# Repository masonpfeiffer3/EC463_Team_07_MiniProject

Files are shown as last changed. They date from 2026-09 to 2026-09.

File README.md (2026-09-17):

# 07-Miniproject
[Demo Link](https://drive.google.com/file/d/174wR8b0HiahtT9Z3u5mZbhheMCSKgrk_/view?usp=sharing)

[Project Board Link (responsibilities listed here)](https://app.notion.com/p/Mini-Project-Board-3da2b21b7a02809690e9f732688cc1ad?source=copy_link)

## Product Photo

<p align="center">
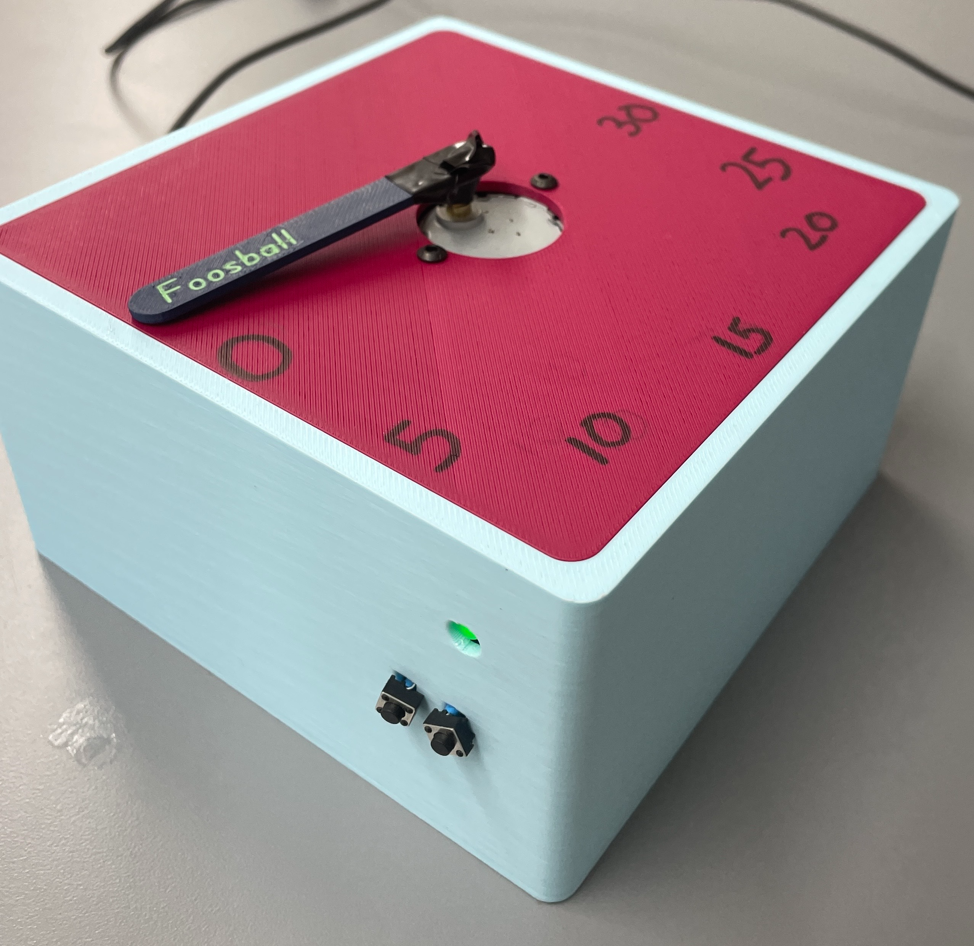
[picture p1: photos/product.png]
  
</p>

## How to Use

The device has two buttons (A and B) and one RGB status LED. On power-up the pointer is assumed to be parked at the home/reset position (0°).

1. **Idle / Time Select** — LED glows steady green.
   - Press **Button A** to cycle through the four presets (15, 20, 25, 30 min). Each press drives the stepper motor to move the pointer to that preset's angle.
   - Press **Button B** to start the countdown for the currently selected preset.
2. **Count Down** — LED flashes green.
   - The pointer sweeps continuously from the preset angle back toward the home position over the course of the countdown, arriving back at 0° exactly at timeout.
   - Press **Button A** to reset immediately (pointer returns home, state returns to idle).
   - Press **Button B** to pause.
3. **Pause** — LED flashes red/green.
   - Press **Button A** to reset (pointer returns home).
   - Press **Button B** to resume the countdown from where it left off.

### Building blocks demonstrated

- **GPIO** — both buttons are read as debounced digital inputs, and the microcontroller's output pins drive the L293D motor driver's control lines; GPIO is the foundation every other subsystem (motor, LED, buttons) is built on.
- **PWM** — the RGB LED's steady/flashing states are produced by driving each color's GPIO pin with a PWM duty cycle that ramps up and down (`PulsingRGB` in `firmware/angle_config.py`, prototyped in `firmware/led.py`).
- **Motor control** — a 28BYJ-48 stepper motor, wave-driven through an L293D H-bridge (`Stepper28BYJ48` in `firmware/angle_config.py`), moves the clock-hand pointer to precise preset angles and sweeps it proportionally during the countdown.
- **Low-power operation** — the stepper's coils are de-energized (`release()`) as soon as a move completes, so the motor only draws current (and generates heat) while actively stepping rather than continuously holding torque at a fixed position.

## Repository Structure

```
.
├── firmware/                # Micro source code
├── Hardware/
│   ├── Electrical/          # Schematics, wiring diagrams, and component docs
│   └── Mechanical/          # Enclosure CAD/STL files and drawings
├── photos/                  # All project images (schematics, CAD drawings, product photos, etc.)
└── README.md
```

## Flow Chart & Electrical Schematic

<p align="center">
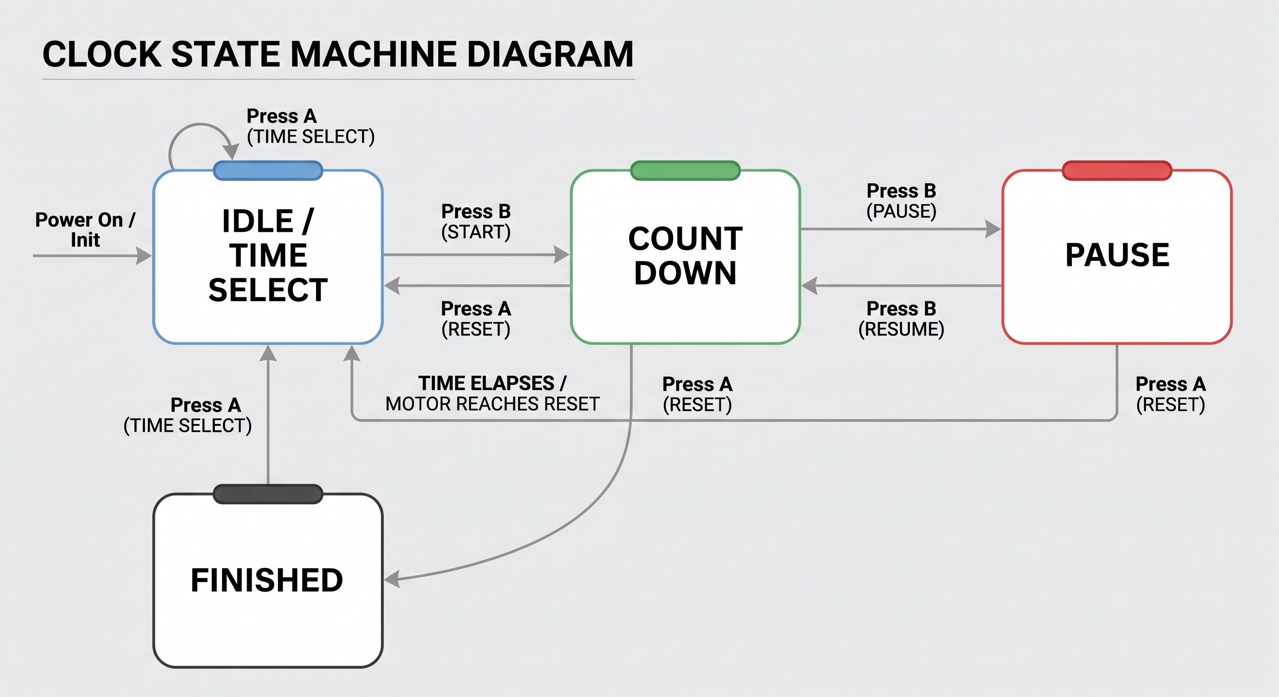
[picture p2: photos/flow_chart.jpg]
  
  
</p>

## Approach & Progress

After setting up the team repo with a branch protection ruleset for `main`, development started on the breadboard circuitry needed to interface with the embedded hardware alongside the software prototype.

This was built up one step at a time:

1. Verified the ESP32-S3 could be flashed via Thonny MicroPython with a simple blink test on the onboard LED.
2. Wired the necessary GPIO pins to the motor controller, including grounding, supplying voltage, and tying the enable pins high, then connected the motor to the controller.
3. Tested with a simple script that spun the motor 90° back and forth based on its gear ratio.
4. Attached the push buttons to additional I/O and continuously ran the motor until a button press was detected (with software debouncing) — one button reverses direction, the other pauses/resumes motion.
5. Connected 3 GPIO pins to each RGB LED anode prong (through resistors) and grounded the cathode, then drove PWM signals to the GPIO pins to experiment with flashing frequencies.
6. Implemented the finite state machine for operation — the core of the project. With all other embedded components functioning, wiring up the clock-specific use case was trivial beyond the state machine itself.

The software/embedded prototype now exists, and the rest of the team can carry it forward to the final version.

### Design Intentionality and Tradeoffs

| State | LED | Button A | Button B |
|---|---|---|---|
| Idle / Time Select | Blue | Time select | Start |
| Count Down | Green | Reset | Pause |
| Pause | Red | Reset | Resume |

In the idle state, the pointer indicates the selected time in 360°/5 = 72° increments (requiring a clock face labeled at each position). Upon start, the pointer moves from the selected time position to the reset position. There are 5 total positions — 4 time options plus the reset position.

There are multiple ways to lay out these positions, and the tradeoff considered here is that total movement isn't proportional to the selected time (15 min is 72° from reset, 20 min is 144°, etc.), but functionally the user can still gauge the proportion of time that has passed since the timer started.

<p align="center">
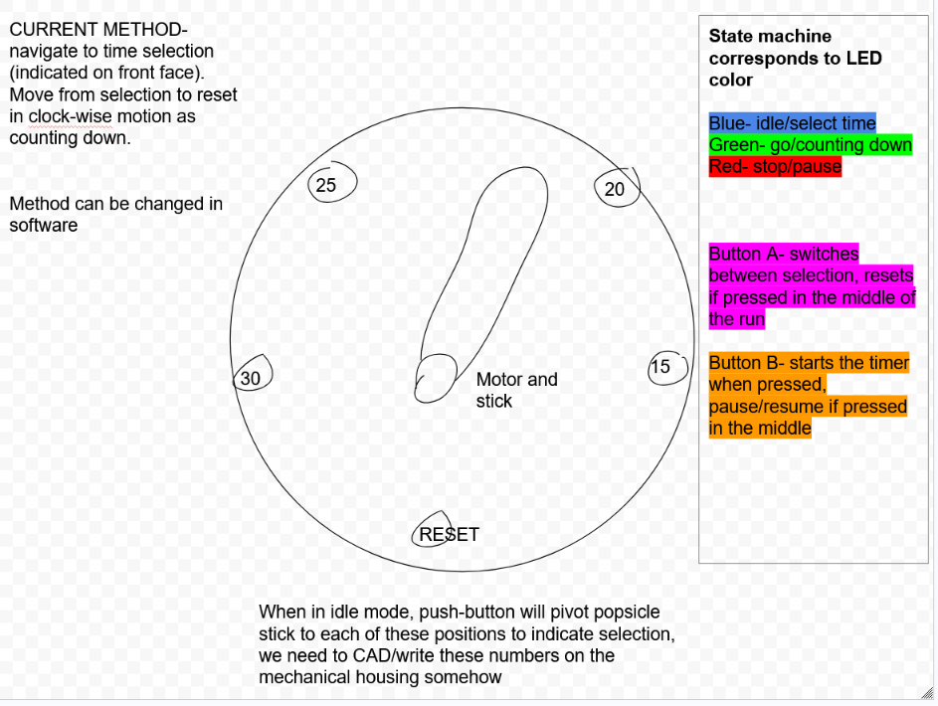
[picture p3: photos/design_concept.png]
  
</p>

**Update:** the final version changed this so the countdown is proportional. Even though only 15/20/25/30 are selectable times, the dial reserves the space for 5 and 10 minutes between each selection and the reset (0) position — so the pointer's distance from reset always reflects how much time is actually left, regardless of which time was selected.

## Team

| Role | Named Members |
|---|---|
| Mechanical Housing | Lana Kader, Niyati Patel, Arham Mufti |
| Electrical Wiring | Lana Kader, Mason Pfeiffer, Ethan Manfredi |
| uController Firmware | Darwin Quizhpi, Phillip Omohundro, Mason Pfeiffer, Ethan Manfredi |

[Project Board Link (responsibilities listed here)](https://app.notion.com/p/Mini-Project-Board-3da2b21b7a02809690e9f732688cc1ad?source=copy_link)

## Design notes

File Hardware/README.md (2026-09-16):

## Hardware

This folder is divided into two sections:

* **[Electrical](./Electrical/)** — schematics, wiring, and the electronic components used (microcontroller, motor driver, LEDs, buttons).
* **[Mechanical](./Mechanical/)** — enclosure CAD/STL files and drawings.

See each subfolder's README for details.

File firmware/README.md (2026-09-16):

Flow Chart

this folder contains firmware that to flash to the ESP32 S3, in order of development prototyping

**`angle_config.py` is the actual/final firmware.** `stepper.py`, `push_button.py`, `led.py`, and `state_machine.py` are earlier iterations kept for reference — each one built up a single piece (motor motion, button input, LED, then the combined state machine) on the way to the final version.

1. stepper.py drives the stepper 90 degrees back and forth
2. push_button.py actively runs the motor and reverses it's direction upon button press
3. led.py flashes the LED between it's colors using PWM
4. state_machine.py combines these features to create the timer
5. angle_config.py is the final version — same state machine, but with proportional preset angles (see below)

state machine-
- LED color corresponds to state
- blue = idle (one button cycles through time select, the other starts)
- green = active (one button resets it, the other pauses)
- red = paused (one button resets it, the other resumes)

Each time has it's own position, as well as the reset position, which upon starting the stepper motor moves toward.
5 total positions- 15, 20, 25, 30, and the reset position.

In the final version (`angle_config.py`), each preset's angle is proportional to its duration (6° per minute: 15 min = 90°, 20 min = 120°, 25 min = 150°, 30 min = 180°), so the hand's distance from the reset position always reflects how much time is actually remaining, not just which preset was picked.

stepper.py-
The firmware file stepper.py contains a test for the micro controller that is intended to turn the stepper motor 90º in one direction and then 90º back to its original position. This test allows us to ensure that our wiring is correct and that we engage the correct motor pins to allow us to move the motor.

At the top of the file is the pinout that specifies which GPIO port is connected to which pin and which wire each of those pins is connected to. We then define the steps per revolution which is needed to specify how much each step rotates the rod.

Finally, we execute the rotation, turning 90º in the positive direction before pausing and turning back

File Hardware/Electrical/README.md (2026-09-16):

# Wiring schematic 

<p align="center">

</p>

# Parts Used in the Project

<p align="center">
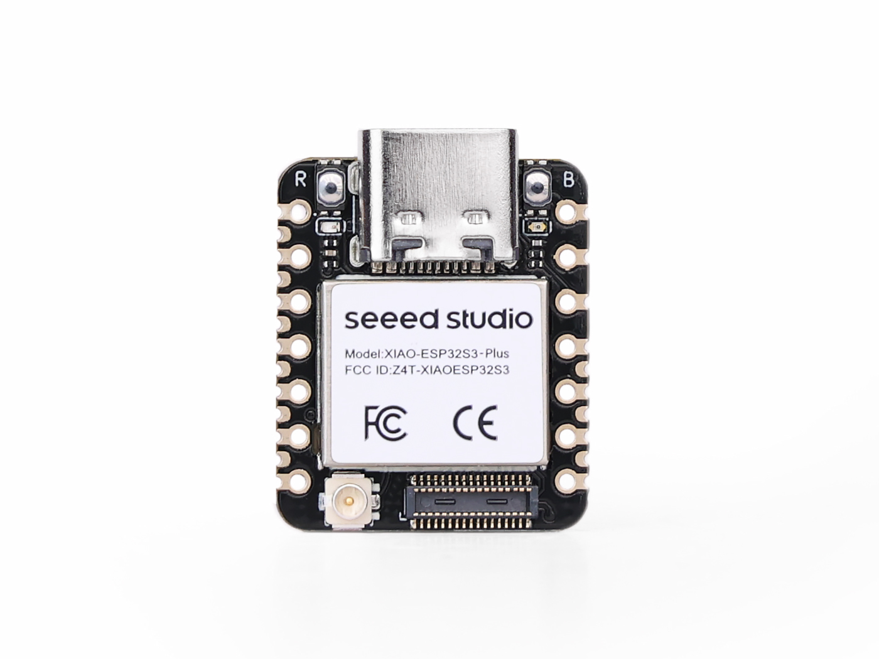
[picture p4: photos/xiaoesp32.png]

</p>

<p align="center">
<strong>XIAO ESP32-S3</strong>
</p>

The XIAO ESP32-S3 is the main microcontroller used in the project. It runs the program and controls the other components by reading inputs and sending output signals.

---

<p align="center">
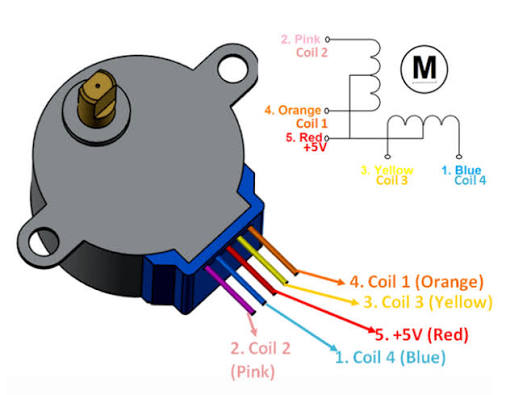
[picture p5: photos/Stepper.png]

</p>

<p align="center">
<strong>28BYJ-48 Stepper Motor</strong>
</p>

The 28BYJ-48 is a small stepper motor that can rotate in precise steps. It is used when controlled movement and positioning are needed.

---

<p align="center">
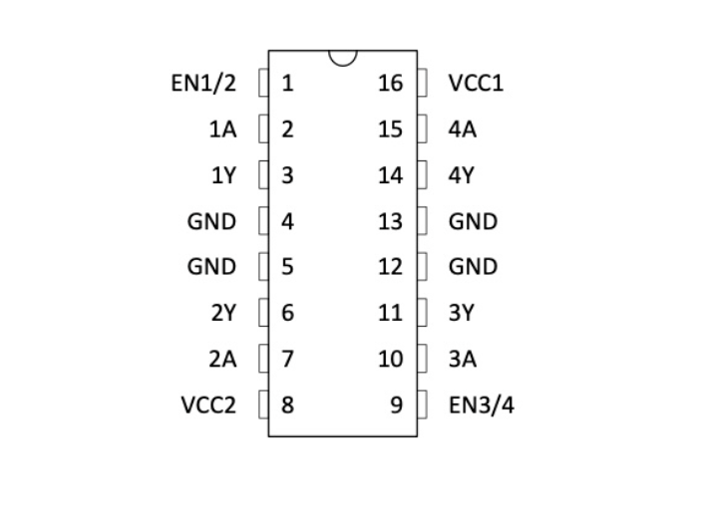
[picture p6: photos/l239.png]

</p>

<p align="center">
<strong>L293 Motor Driver</strong>
</p>

The L293 is a motor driver used between the ESP32 and the stepper motor. It allows the microcontroller to control the motor while providing the higher current required by the motor.

---

<p align="center">
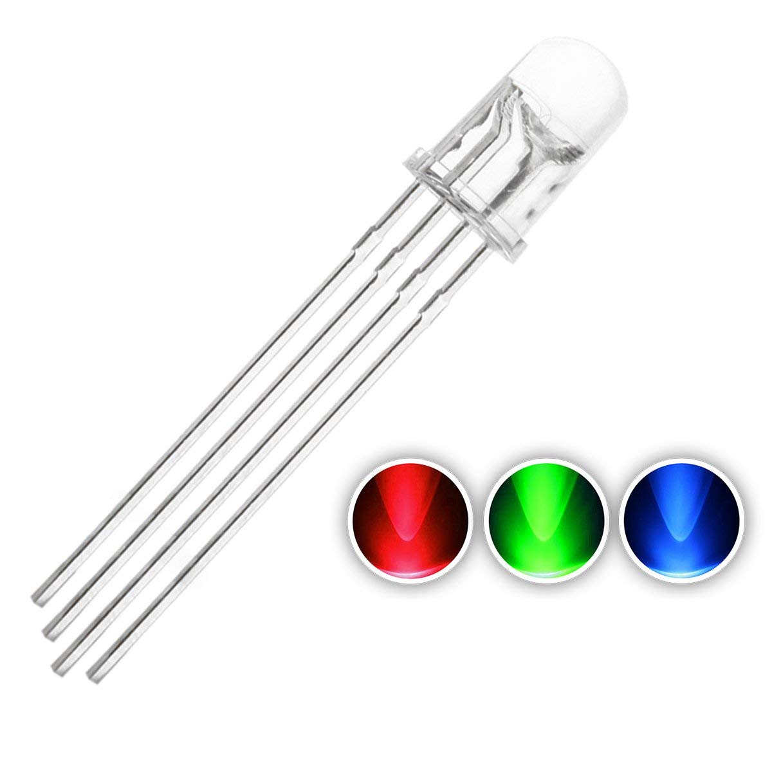
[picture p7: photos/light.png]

</p>

<p align="center">
<strong>4-Pin RGB LED</strong>
</p>

The RGB LED contains red, green, and blue LEDs in one package. By controlling each color individually, it can display different colors and provide visual feedback about the system.

---

<p align="center">
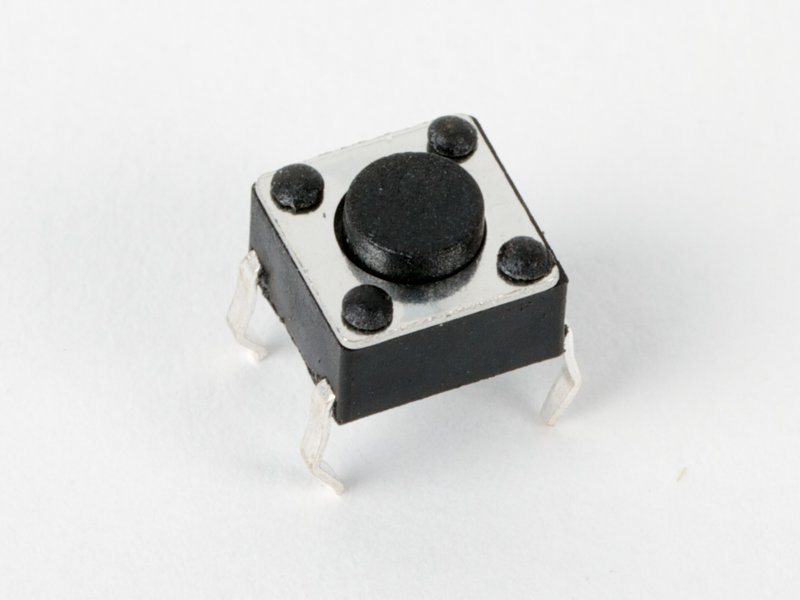
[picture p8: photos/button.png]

</p>

<p align="center">
<strong>Push Buttons</strong>
</p>

Two push buttons are used as user inputs. When pressed, they send a signal to the ESP32 so the program can perform a specific action.

# How These Parts Were Connected

Connections:

| Component | Connected To |
|---|---|
| XIAO GPIO1–4 | L293D inputs (1A, 2A, 3A, 4A) |
| L293D outputs (1Y, 2Y, 3Y, 4Y) | Stepper motor coils (Orange, Pink, Yellow, Blue) |
| Motor red wire | +5V |
| L293D Pin 16 (VCC1) | +3.3V (logic power) |
| L293D Pin 8 (VCC2) | +5V (motor power) |
| L293D Pins 1 & 9 (EN) | +3.3V (enables motor channels) |
| L293D Pins 4, 5, 12, 13 | GND |
| XIAO GPIO7 | Red LED (through 220Ω resistor) |
| XIAO GPIO8 | Blue LED (through 220Ω resistor) |
| XIAO GPIO9 | Green LED (through 220Ω resistor) |
| XIAO GPIO5 | Button 1 |
| XIAO GPIO6 | Button 2 |
| All GND pins | Common ground |
| Stepper motor shaft | Popsicle stick (clock hand) |

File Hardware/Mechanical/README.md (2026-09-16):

# Mechanical Design

<p align="center">
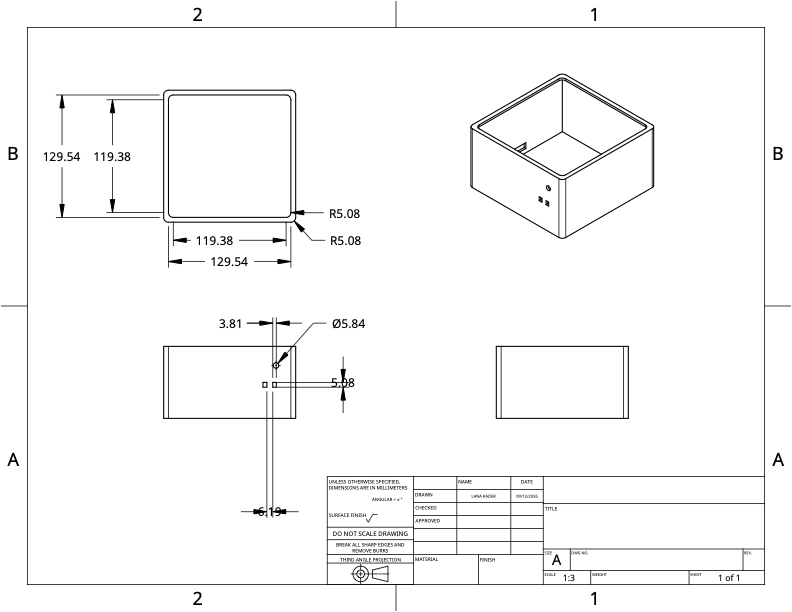
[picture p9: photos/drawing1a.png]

</p>

<p align="center">
<strong>Main Box Enclosure Drawing</strong>
</p>

<p align="center">
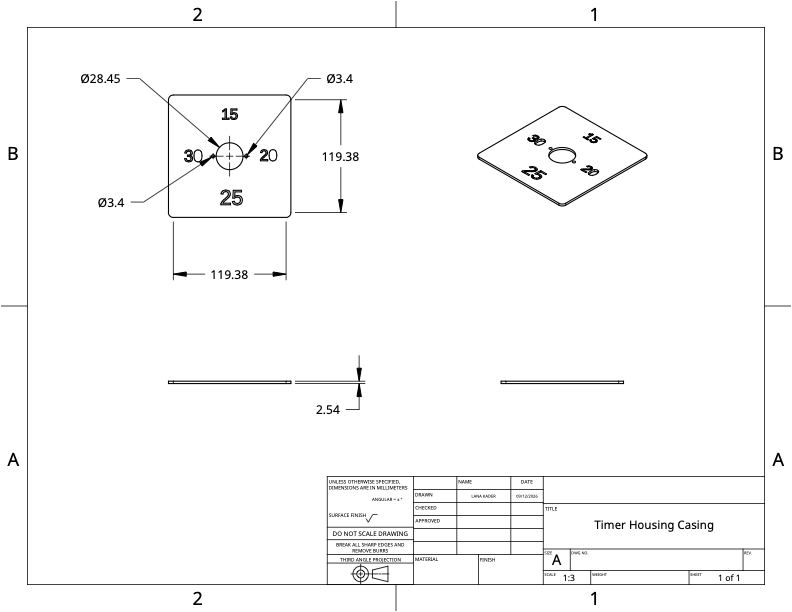
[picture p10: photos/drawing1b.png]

</p>

<p align="center">
<strong>Top of Box Drawing</strong>
</p>

The mechanical portion of the project focuses mainly on the design and construction of the enclosure that holds and supports the electrical components.

The enclosure was designed in CAD as a simple box with a removable top. Its purpose is to keep the breadboard and wiring contained while also providing mounting points and openings for the components that need to be accessible from the outside.

## Enclosure Design

The main body of the enclosure is designed to hold the breadboard and the majority of the wiring used in the project.

Several openings were added to the enclosure so that the electrical components can be accessed without needing to open the box.

These include:

* Holes for the push buttons
* An opening for the RGB LED
* Space inside the enclosure for the breadboard and wiring
* Openings needed to route or position electrical components

The buttons are positioned so that they can be pressed from outside the enclosure while still remaining connected to the breadboard inside.

The RGB LED is also mounted through the enclosure so that its light can be clearly seen while the rest of the electrical hardware remains protected inside.

## Top Cover

The top cover of the enclosure was designed to support the stepper motor used in the project.

A hole in the cover allows the motor shaft to extend through the top of the enclosure. There is also two holes in which two screws and nuts can be connected through the motor to safely attach to the top. A pointer, or stick, is attached to the motor shaft and rotates with the motor.

The pointer is used to indicate different positions marked on the top surface of the enclosure. As the stepper motor rotates to specific angles, the pointer moves to the corresponding position.

This allows the motion of the motor to be turned into a simple visual display while keeping the motor and electrical connections mostly contained inside the enclosure.

## CAD Drawings

The CAD drawings above document the dimensions and geometry of the enclosure and its individual parts.

The design consists mainly of:

* The main enclosure body
* The removable top cover
* Button mounting holes
* RGB LED opening
* Stepper motor shaft opening
* Space for the internal breadboard and wiring

These drawings can be used to reproduce or modify the enclosure if changes to the project are needed later.

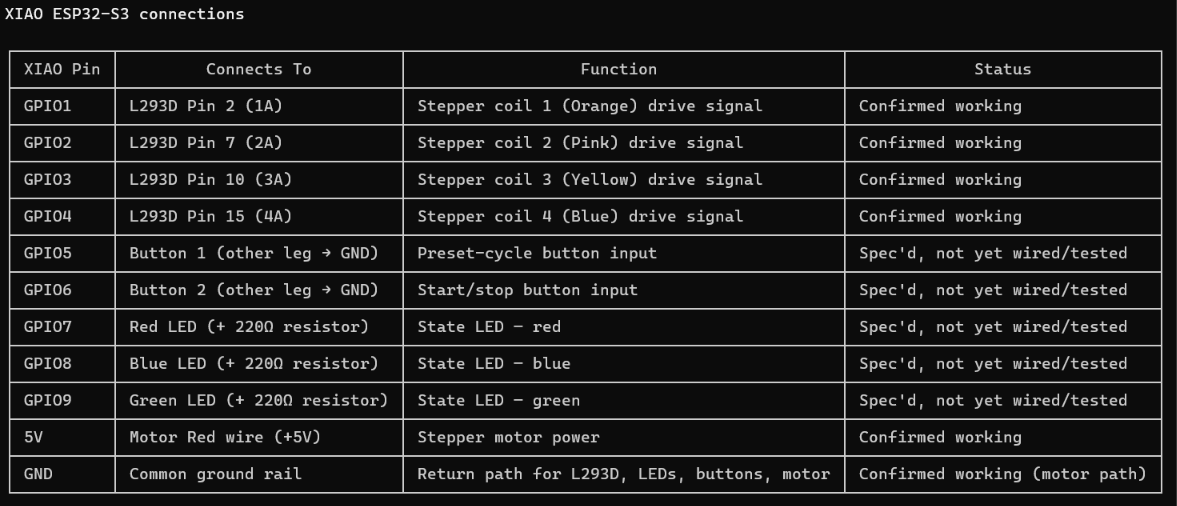
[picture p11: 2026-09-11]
photos/Screenshot 2026-09-10 180326.png

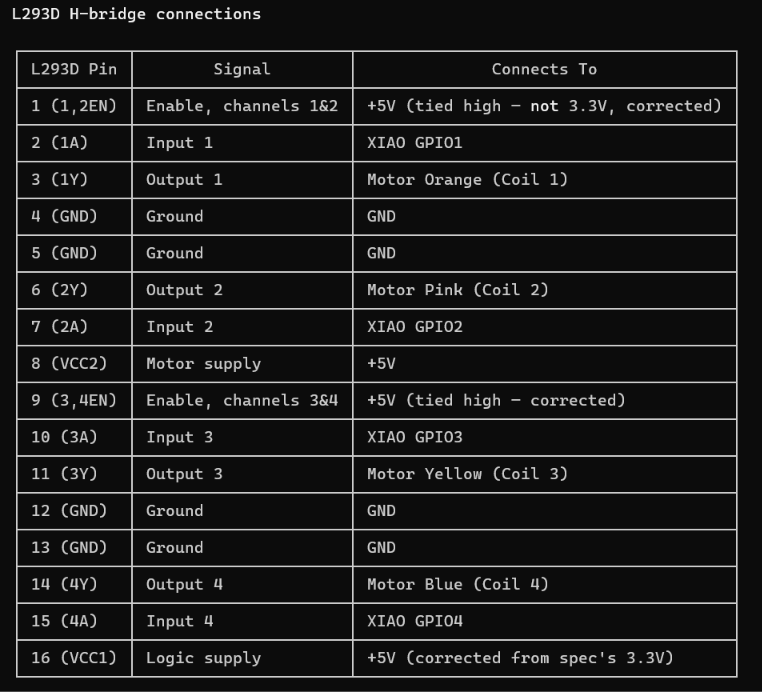
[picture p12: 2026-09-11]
photos/Screenshot 2026-09-10 180338.png

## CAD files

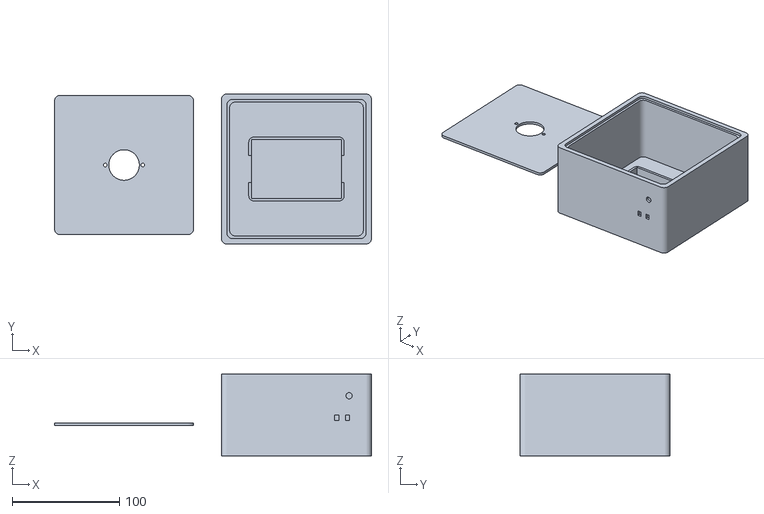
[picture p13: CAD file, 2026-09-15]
Hardware/Mechanical/Assembly 1.stl
295.2 x 139.7 x 76.2

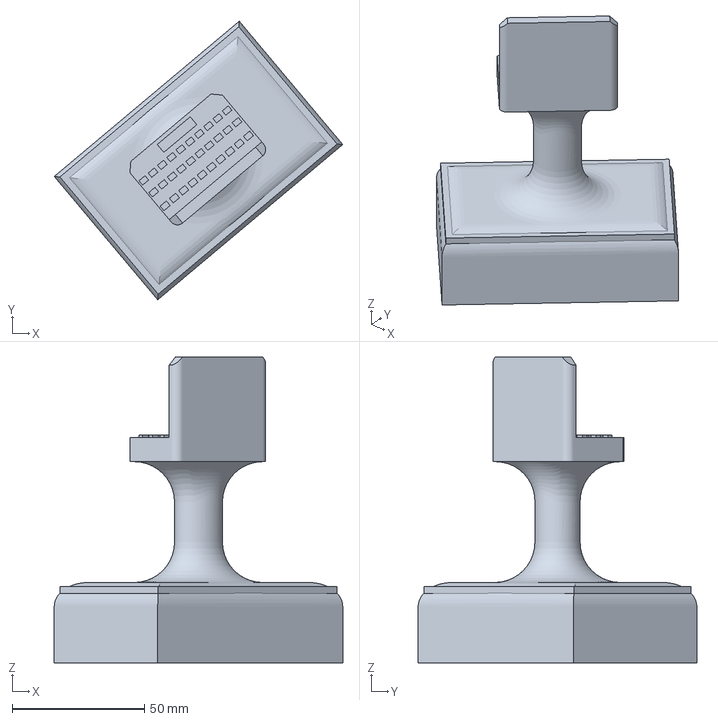
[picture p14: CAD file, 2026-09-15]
Hardware/Mechanical/trophy.3mf
109.2 x 105.5 x 115.8 mm

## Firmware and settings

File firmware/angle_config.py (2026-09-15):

"""
Meeting timer state machine for XIAO ESP32-S3 (MicroPython).

States:
    IDLE    -- selecting a preset, hand parked at the preset's position, LED blue
    RUNNING -- counting down, hand sweeping from the preset position back to
               home (0 deg), LED green
    PAUSED  -- countdown frozen in place, LED red

Stepper positions, 5 presets, starting at 90º from home pos, and incrementing by 30º until 180º from home pos
    0 deg   -- home / reset position
    90 deg  -- 15 min preset
    120 deg -- 20 min preset
    150 deg -- 25 min preset
    180 deg -- 30 min preset
Angle can be changed in the PREST_CONFIG array in the state machine block

While RUNNING, the hand sweeps continuously from its preset angle down to
0 deg over the preset's duration, arriving at 0 deg exactly at timeout --
timeout and reset land on the same physical position by design.

Buttons (see firmware/README for pin table):
    GPIO5 (Button 1) -- IDLE: cycle preset selection | RUNNING/PAUSED: reset to home
    GPIO6 (Button 2) -- IDLE: start countdown        | RUNNING/PAUSED: pause/resume

LED (common-cathode RGB, GPIO7=Red, GPIO8=Blue, GPIO9=Green), pulsing ~1s period:
    IDLE = blue, RUNNING = green, PAUSED = red

Known simplifications:
    - No homing sensor: the hand is assumed to be physically parked at the
      home/reset position when the board powers on.
    - Moving to a new preset (idle select) or resetting are done as a single
      blocking move -- buttons aren't polled mid-move for those two actions.
"""

from machine import Pin, PWM
import utime

# ---- Stepper ----------------------------------------------------------

class Stepper28BYJ48:
    # Wave drive sequence: one coil high at a time. 1-3-2-4 order (not 1-2-3-4)
    # avoids jitter-in-place on this specific 28BYJ-48 unit.
    _SEQUENCE = (
        (1, 0, 0, 0),
        (0, 0, 1, 0),
        (0, 1, 0, 0),
        (0, 0, 0, 1),
    )
    STEPS_PER_REV = 2048

    def __init__(self, pins=(1, 2, 3, 4), step_delay_ms=3):
        self._coils = [Pin(p, Pin.OUT) for p in pins]
        self.step_delay_ms = step_delay_ms
        self._index = 0
        self.angle = 0.0  # assumed home at power-on, see module docstring
        self._write((0, 0, 0, 0))

    def _write(self, state):
        for coil, value in zip(self._coils, state):
            coil.value(value)

    def step(self, direction):
        """Advance one step. direction: +1 = forward, -1 = reverse."""
        self._index = (self._index + direction) % len(self._SEQUENCE)
        self._write(self._SEQUENCE[self._index])
        self.angle = (self.angle + direction * 360.0 / self.STEPS_PER_REV) % 360.0
        utime.sleep_ms(self.step_delay_ms)

    def release(self):
        self._write((0, 0, 0, 0))

    def move_to(self, target_deg):
        """Blocking move to an absolute angle via the shortest direction."""
        diff = (target_deg - self.angle + 540) % 360 - 180
        steps = round(diff * self.STEPS_PER_REV / 360.0)
        direction = 1 if steps >= 0 else -1
        for _ in range(abs(steps)):
            self.step(direction)
        self.angle = target_deg % 360.0  # snap, avoids rounding drift
        self.release()


# ---- Button ------------------------------------------------------------

class DebouncedButton:
    """Time-based hysteresis debounce for a single active-low GPIO button."""

    def __init__(self, pin_num, debounce_ms=30):
        self._pin = Pin(pin_num, Pin.IN, Pin.PULL_UP)
        self._debounce_ms = debounce_ms
        self._raw = self._pin.value()
        self._stable = self._raw
        self._last_change_ms = utime.ticks_ms()

    def pressed(self):
        """Returns True once per press (stable release -> pressed transition)."""
        raw = self._pin.value()
        now = utime.ticks_ms()

        if raw != self._raw:
            self._raw = raw
            self._last_change_ms = now

        edge = False
        if utime.ticks_diff(now, self._last_change_ms) >= self._debounce_ms and self._raw != self._stable:
            self._stable = self._raw
            edge = self._stable == 0  # 0 = pressed (active low)

        return edge


# ---- LED -----------------------------------------------------------------

PULSE_PERIOD_MS = 1000


class PulsingRGB:
    """Non-blocking breathing pulse on one of three PWM channels at a time."""

    def __init__(self, red_pin, blue_pin, green_pin):
        self._channels = {
            "red": PWM(Pin(red_pin), freq=1000, duty_u16=0),
            "blue": PWM(Pin(blue_pin), freq=1000, duty_u16=0),
            "green": PWM(Pin(green_pin), freq=1000, duty_u16=0),
        }
        self._active = None

    def set_color(self, color):
        if color != self._active:
            for name, pwm in self._channels.items():
                pwm.duty_u16(0)
            self._active = color

    def update(self, now_ms):
        """Call every loop iteration to advance the pulse."""
        if self._active is None:
            return
        half = PULSE_PERIOD_MS // 2
        phase = now_ms % PULSE_PERIOD_MS
        level = phase / half if phase < half else (PULSE_PERIOD_MS - phase) / half
        self._channels[self._active].duty_u16(int(65535 * level))


# ---- State machine ---------------------------------------------------

IDLE, RUNNING, PAUSED = "IDLE", "RUNNING", "PAUSED"

# TESTING ONLY: durations are in seconds here (15/20/25/30s) instead of
# minutes so bring-up doesn't require waiting through a real countdown.
# Revert to minutes (and restore the *60*1000 conversion below) before demo.

PRESET_CONFIG = {
    1: (15, 90),
    2: (20, 120),
    3: (25, 150),
    4: (30, 180),
}

if __name__ == "__main__":
    motor = Stepper28BYJ48(pins=(1, 2, 3, 4), step_delay_ms=3)
    button_select_reset = DebouncedButton(5)
    button_start_pause = DebouncedButton(6)
    led = PulsingRGB(red_pin=7, blue_pin=8, green_pin=9)

    state = IDLE
    preset_index = 0  # 0 = none selected / home, 1-4 = preset slot
    steps_remaining = 0
    step_interval_ms = 0.0
    active_elapsed_ms = 0.0

    led.set_color("blue")
    print("Idle. Button1 (GPIO5) selects a preset / resets, Button2 (GPIO6) starts/pauses/resumes.")

    last_loop_ms = utime.ticks_ms()

    while True:
        now = utime.ticks_ms()
        dt = utime.ticks_diff(now, last_loop_ms)
        last_loop_ms = now

        if state == IDLE:
            if button_select_reset.pressed():
                preset_index = (preset_index % 4) + 1
                seconds, angle = PRESET_CONFIG[preset_index]
                motor.move_to(angle)
                print("Selected preset:", PRESET_CONFIG[preset_index], "s (testing units)")

            elif button_start_pause.pressed():
                if preset_index != 0:
                    seconds, angle = PRESET_CONFIG[preset_index]
                    steps_remaining = round(angle * Stepper28BYJ48.STEPS_PER_REV / 360.0)
                    step_interval_ms = (seconds * 1000) / steps_remaining
                    active_elapsed_ms = 0.0
                    state = RUNNING
                    led.set_color("green")
                    print("Started:", seconds, "s countdown")
                else:
                    print("No preset selected -- press Button1 first")

        elif state == RUNNING:
            if button_select_reset.pressed():
                motor.move_to(0)
                state = IDLE
                preset_index = 0
                steps_remaining = 0
                active_elapsed_ms = 0.0
                led.set_color("blue")
                print("Reset")

            elif button_start_pause.pressed():
                state = PAUSED
                led.set_color("red")
                print("Paused")

            else:
                active_elapsed_ms += dt
                while steps_remaining > 0 and active_elapsed_ms >= step_interval_ms:
                    motor.step(-1)
                    steps_remaining -= 1
                    active_elapsed_ms -= step_interval_ms

                if steps_remaining == 0:
                    state = IDLE
                    preset_index = 0
                    active_elapsed_ms = 0.0
                    led.set_color("blue")
                    print("Timer complete")

        elif state == PAUSED:
            if button_select_reset.pressed():
                motor.move_to(0)
                state = IDLE
                preset_index = 0
                steps_remaining = 0
                active_elapsed_ms = 0.0
                led.set_color("blue")
                print("Reset")

            elif button_start_pause.pressed():
                state = RUNNING
                led.set_color("green")
                print("Resumed")

        led.update(now)
        utime.sleep_ms(5)

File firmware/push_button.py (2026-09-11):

"""
Continuous stepper drive with button-controlled direction toggle and
button-controlled start/stop, for XIAO ESP32-S3 running MicroPython.

Pinout:
    GPIO1 -> L293D Pin 2  (1A) -> L293D Pin 3  (1Y) -> Motor Orange (Coil 1)
    GPIO2 -> L293D Pin 7  (2A) -> L293D Pin 6  (2Y) -> Motor Pink   (Coil 2)
    GPIO3 -> L293D Pin 10 (3A) -> L293D Pin 11 (3Y) -> Motor Yellow (Coil 3)
    GPIO4 -> L293D Pin 15 (4A) -> L293D Pin 14 (4Y) -> Motor Blue   (Coil 4)
    GPIO5 -> Button 1 (start/stop), other leg -> GND (uses internal pull-up, active low)
    GPIO6 -> Button 2 (direction), other leg -> GND (uses internal pull-up, active low)
"""

from machine import Pin
import utime


class Stepper28BYJ48:
    # Wave drive sequence: one coil high at a time. Reversing this list reverses direction.
    # NOTE: order is 1-3-2-4, not 1-2-3-4 -- the 28BYJ-48's coil pairs aren't wired
    # in physical winding order by wire label, so straight sequential activation
    # causes jitter-in-place instead of rotation.
    _SEQUENCE = (
        (1, 0, 0, 0),
        (0, 0, 1, 0),
        (0, 1, 0, 0),
        (0, 0, 0, 1),
    )

    def __init__(self, pins=(1, 2, 3, 4), step_delay_ms=3):
        self._coils = [Pin(p, Pin.OUT) for p in pins]
        self.step_delay_ms = step_delay_ms
        self._index = 0
        self._write((0, 0, 0, 0))

    def _write(self, state):
        for coil, value in zip(self._coils, state):
            coil.value(value)

    def step(self, direction):
        """Advance one step. direction: +1 = forward, -1 = reverse."""
        self._index = (self._index + direction) % len(self._SEQUENCE)
        self._write(self._SEQUENCE[self._index])
        utime.sleep_ms(self.step_delay_ms)

    def release(self):
        """De-energize all coils (cuts current draw / heat while stopped)."""
        self._write((0, 0, 0, 0))


class DebouncedButton:
    """Time-based hysteresis debounce for a single active-low GPIO button."""

    def __init__(self, pin_num, debounce_ms=30):
        self._pin = Pin(pin_num, Pin.IN, Pin.PULL_UP)
        self._debounce_ms = debounce_ms
        self._raw = self._pin.value()
        self._stable = self._raw
        self._last_change_ms = utime.ticks_ms()

    def pressed(self):
        """Returns True once per press (stable release -> pressed transition)."""
        raw = self._pin.value()
        now = utime.ticks_ms()

        if raw != self._raw:
            self._raw = raw
            self._last_change_ms = now

        edge = False
        if utime.ticks_diff(now, self._last_change_ms) >= self._debounce_ms and self._raw != self._stable:
            self._stable = self._raw
            edge = self._stable == 0  # 0 = pressed (active low)

        return edge


if __name__ == "__main__":
    motor = Stepper28BYJ48(pins=(1, 2, 3, 4), step_delay_ms=3)
    button_run = DebouncedButton(5)
    button_dir = DebouncedButton(6)
    direction = 1
    running = True

    print("Running. Button 1 (GPIO5) = start/stop, Button 2 (GPIO6) = reverse direction.")

    while True:
        if button_run.pressed():
            running = not running
            print("Started" if running else "Stopped")
            if not running:
                motor.release()

        if button_dir.pressed():
            direction *= -1
            print("Direction reversed:", "forward" if direction == 1 else "reverse")

        if running:
            motor.step(direction)
        else:
            utime.sleep_ms(10)

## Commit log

2026-09-10 driving stepper motor with stepper.py
2026-09-10 wire connections included
2026-09-10 Enhance README with stepper motor test details
    Expanded the README to provide detailed information about the stepper motor test and pinout configuration.
2026-09-10 Add initial schematic file
2026-09-10 both push-buttons working and LED PWM in isolation
2026-09-13 CAD File and 2D CAD Drawing
2026-09-13 include new minproject board in README.md
2026-09-14 Add angle_config.py for meeting timer functionality
    change to state_machine.py that aligns with our enclosure and allows for hot-swappable angles and times
    [angle_config.py]
2026-09-15 stl files added
    [Assembly 1.stl, trophy.3mf]
2026-09-15 flow chart added to firmware
2026-09-16 Add demo and project board links to README
